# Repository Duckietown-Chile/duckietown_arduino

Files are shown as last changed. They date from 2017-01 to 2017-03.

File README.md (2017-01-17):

# duckietown_arduino

Arduino based controller for Dukietown robots. This library is based on [serial_dxl](https://github.com/rorromr/serial_dxl).

* Microcontroller: ATmega 168 3.3V 8MHz
* Board: Arduino Pro Mini
* H Bridge: Double L9110

| Pin | Function  |
|-----|---|
| 5 | PWM CHA-1B  |
| 6 | PWM CHB-1B  |
| 11  | PWM CHA-1A  |
| 12  | PWM CHB-1A  |

Registros:

| Address | Type | Size | Function |
|---|---|---|---|
| 6 | uint8_t  | 1 | LED (0: off, 1: on) |
| 7 | int16_t  | 2 | PWM channel 1 (-255 to 255)|
| 9 | int16_t  | 2 | PWM channel 1 (-255 to 255)|

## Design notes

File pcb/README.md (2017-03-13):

# Duckiebot Shield

Raspberry Pi 3 Shied thats provide serial communication with Arduino ProMini 328.
Used in Duckiebot for motors and others sensors communication and control.

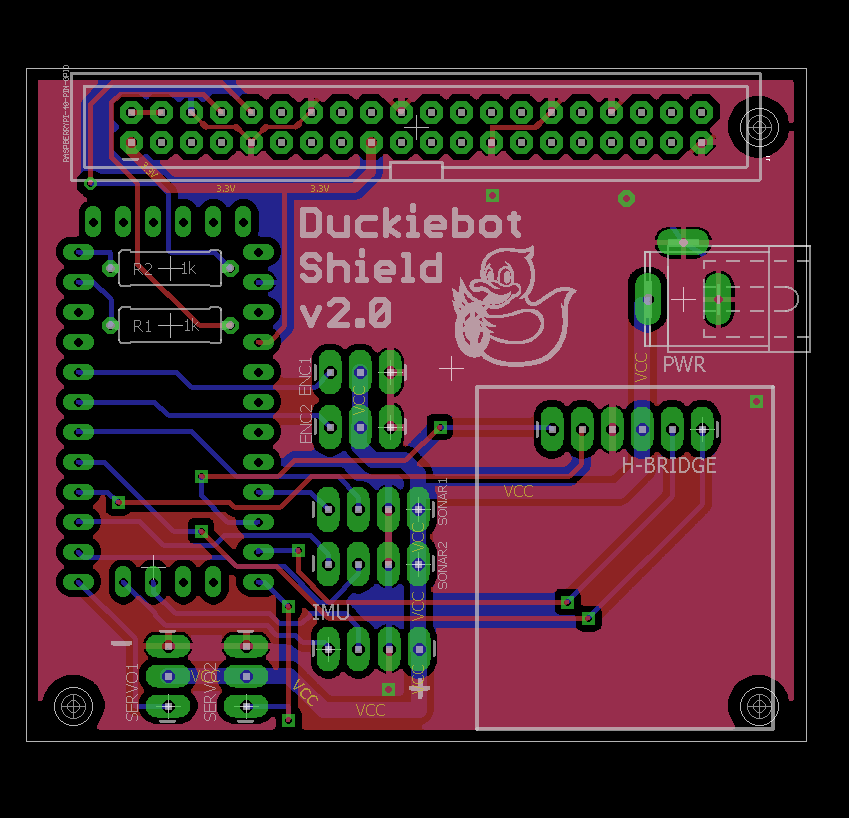
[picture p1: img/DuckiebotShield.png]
duckiebot shield


[duckiebotshield]: https://github.com/Duckietown-Chile/duckietown_arduino/blob/master/img/DuckiebotShield.png

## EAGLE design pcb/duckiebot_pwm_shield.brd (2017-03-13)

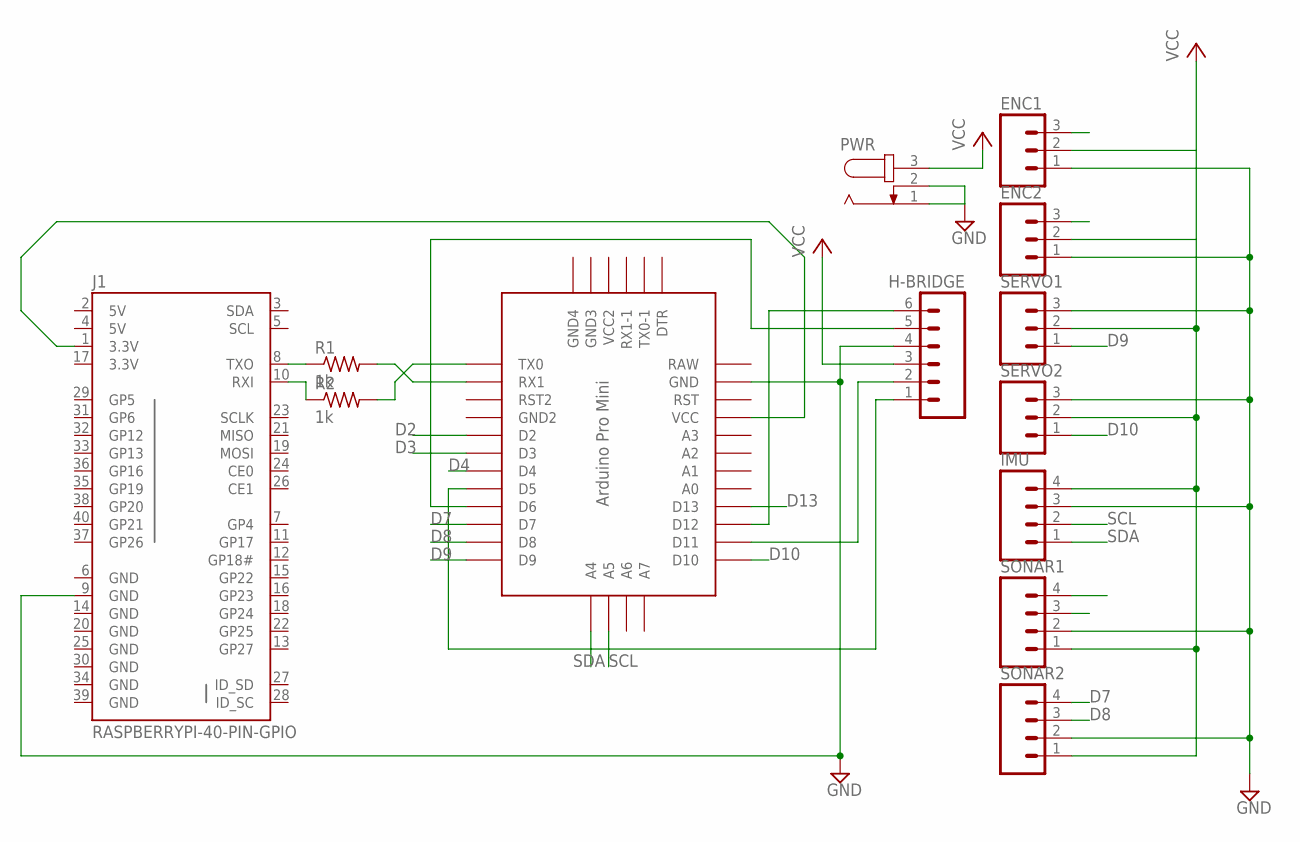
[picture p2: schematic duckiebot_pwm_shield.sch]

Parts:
ENC1, ENC2: M03LONGPADS; 1X03_LONGPADS
H-BRIDGE: M06LONGPADS; 1X06_LONGPADS
IMU: M04LONGPADS; 1X04_LONGPADS
J1: RASPBERRYPI-40-PIN-GPIO; 2X20-SHROUDED
PWR: JACK-PLUG0; SPC4077
R1, R2: 1k; 0309/10
SERVO1, SERVO2: M03LONGPADS; 1X03_LONGPADS
SONAR1, SONAR2: M04LONGPADS; 1X04_LONGPADS
U$2: PRO-MINI

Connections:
3.3V: J1.1 (3.3V), J1.17 (3.3V), U$2.VCC
5V: J1.2 (5V), J1.4 (5V)
A-1A: H-BRIDGE.2, U$2.D11
A-1B: H-BRIDGE.1, U$2.D5
B-1A: H-BRIDGE.6, U$2.D12
B-1B: H-BRIDGE.5, U$2.D6
D2: ENC1.3, U$2.D2
D3: ENC2.3, U$2.D3
D4: SONAR1.3, U$2.D4
D7: SONAR2.4, U$2.D7
D8: SONAR2.3, U$2.D8
D9: SERVO1.1, U$2.D9
D10: SERVO2.1, U$2.D10
D13: SONAR1.4, U$2.D13
GND: ENC1.1, ENC2.1, H-BRIDGE.4, IMU.3, J1.6 (GND), J1.9 (GND), J1.14 (GND), J1.20 (GND), J1.25 (GND), J1.30 (GND), J1.34 (GND), J1.39 (GND), PWR.1, PWR.2, SERVO1.3, SERVO2.3, SONAR1.2, SONAR2.2, U$2.GND
unnamed: R1.2, U$2.RX1
unnamed: R2.2, U$2.TX0
unnamed: J1.10 (RXI), R2.1
unnamed: J1.8 (TXO), R1.1
RAW: U$2.RAW
SCL: IMU.2, U$2.A5
SDA: IMU.1, U$2.A4
VCC: ENC1.2, ENC2.2, H-BRIDGE.3, IMU.4, PWR.3, SERVO1.2, SERVO2.2, SONAR1.1, SONAR2.1

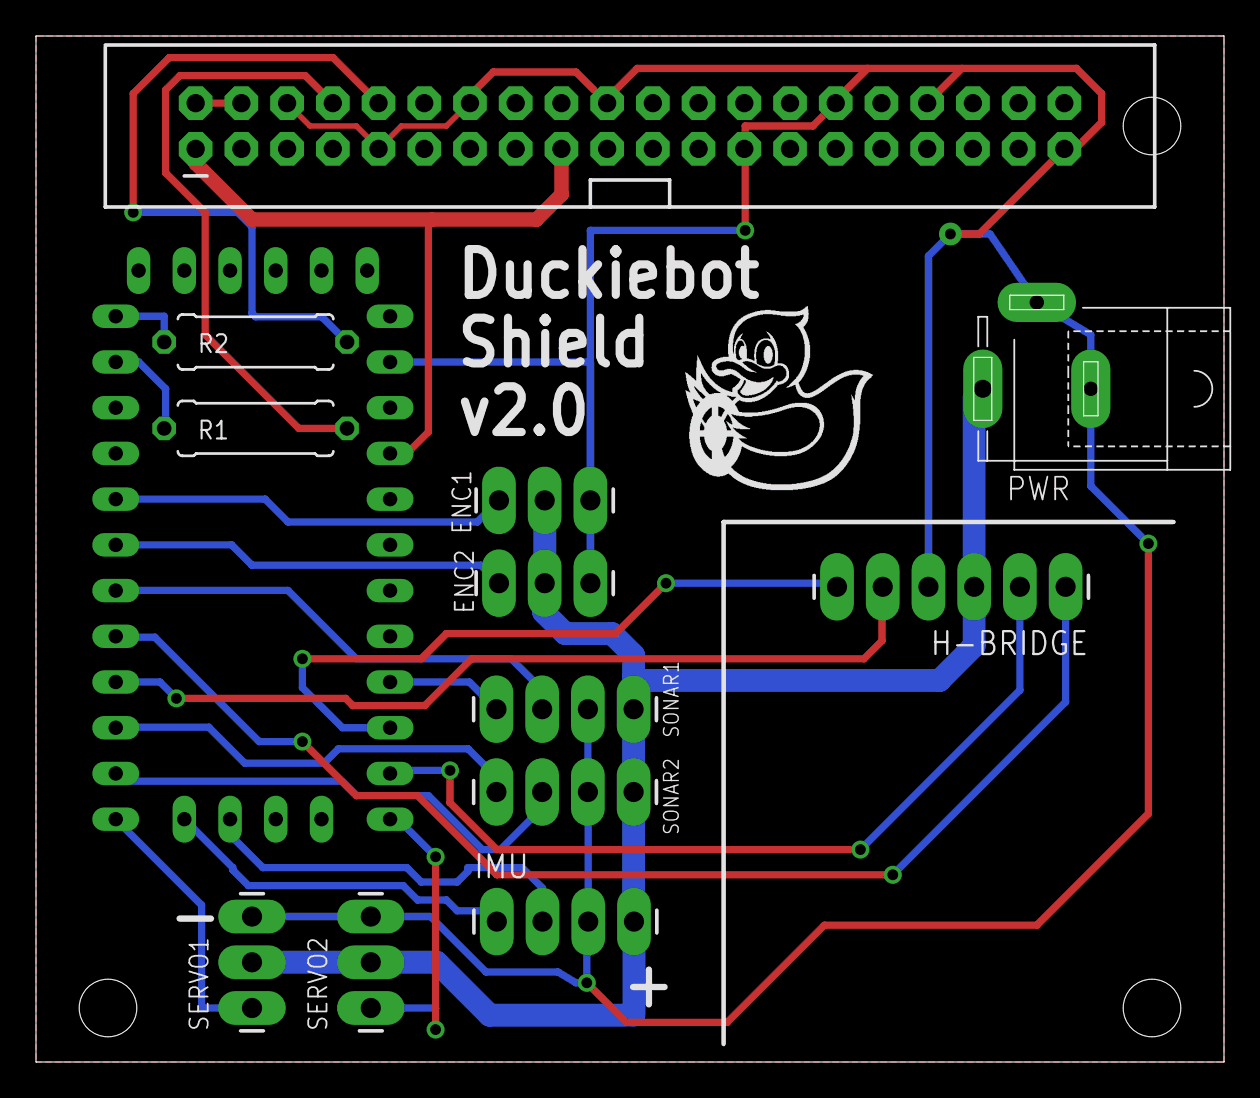
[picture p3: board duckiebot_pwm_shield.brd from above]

Board: 2 copper layers, 66.0 x 57.0 mm, 14 parts (0 on the bottom side), 22 nets.

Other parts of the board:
U$1: DUCK_LOGO

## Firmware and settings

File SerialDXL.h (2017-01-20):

/**
 * @file
 * @brief Dynamixel Device Library
 */
#ifndef SERIALDXL_H
#define SERIALDXL_H

#include "data_serialization.h"
#include "variable.h"
#include "mmap.h"
#include "logger.h"
#include <avr/sleep.h>
#include <Arduino.h>

//------------------------------------------------------------------------------
/**
 * @class DeviceDXL
 * @brief Base class for device with Dynamixel protocol.
 */
template <uint16_t modelT, uint8_t firmwareT, size_t mmap_size>
class DeviceDXL {
  public:
    DeviceDXL():
      model_(MMap::Access::R, MMap::Storage::RAM),
      firmware_(MMap::Access::R, MMap::Storage::RAM),
      id_(MMap::Access::RW, MMap::Storage::RAM),
      baudrate_(MMap::Access::RW, MMap::Storage::RAM),
      return_delay_(MMap::Access::RW, MMap::Storage::RAM),
      mmap_()
    {
    }

    virtual inline bool onReset() = 0;

    virtual inline void setTX() = 0;

    virtual inline void setRX() = 0;

    virtual inline void update() = 0;

    void init()
    {
      mmap_.registerVariable(&model_);
      mmap_.registerVariable(&firmware_);
      mmap_.registerVariable(&id_);
      mmap_.registerVariable(&baudrate_);
      mmap_.registerVariable(&return_delay_);
    }

    void reset()
    {
      if (onReset())
      {
        INFO_PRINTLN("DEVICE RESET");
        mmap_.reset(); // Set default values and save EEPROM
      }
    }

    // Model
    MMap::Variable<UInt16, ConstInt<UInt16::type, 0U>, ConstInt<UInt16::type, 255U>, ConstInt<UInt16::type, modelT> > model_;

    // Firmware version
    MMap::Variable<UInt8, ConstInt<UInt8::type, 0U>, ConstInt<UInt8::type, 255U>, ConstInt<UInt8::type, firmwareT> > firmware_;

    // ID
    MMap::Variable<UInt8, ConstInt<UInt8::type, 0U>, ConstInt<UInt8::type, 255U>, ConstInt<UInt8::type, 1U> > id_;

    // Baudrate
    MMap::Variable<UInt8, ConstInt<UInt8::type, 0U>, ConstInt<UInt8::type, 255U>, ConstInt<UInt8::type, 1U> > baudrate_;

    // Return dalay time
    MMap::Variable<UInt8, ConstInt<UInt8::type, 0U>, ConstInt<UInt8::type, 255U>, ConstInt<UInt8::type, 250U> > return_delay_;

    // Memory mapping
    MMap::MMap<5+mmap_size> mmap_;
};
//------------------------------------------------------------------------------
/**
 * @class SerialDXL
 * @brief Serial port wrapper for DXL communication protocol.
 */

// Max message length, used for buffers
#define SERIALDXL_MSG_LENGTH 64

template <typename DeviceT>
class SerialDXL
{
  public:
    SerialDXL():
      msgState_(0U),
      msgParamIdx_(2U),
      msgLen_(0U),
      msgFinish_(0U),
      msgChecksum_(0U),
      error_(0U),
      last_call_(0UL)
    {
    }

    /**
     * @brief Initialize SerialDXL. Set baudrate and target device.
     * @details 
     * 
     * @param baud Baudrate using Dynamixel format.
     * @param port Serial port (Stream class).
     * @param device Target device.
     */
    void init(HardwareSerial *port, DeviceT *device)
    {
      // Set DeviceDXL
      device_ = device;
      // Set serial port
      port_ = port;
      // Set baudrate using Dynamixel relation
      //uint32_t baud = F_CPU/8/(device_->baudrate_.data+1);
      
      //port_->begin(115200);
      INFO_PRINT("Baudrate at: "); INFO_PRINTLN(9600);
    }

    /**
     * @brief Process data from Serial 
     * @details Add data to buffers
     * 
     * @param data Data from Serial port.
     */
    void process(uint8_t data)
    {
      DEBUG_PRINTLN(data);
      // Check message
      uint32_t now = millis();
      if (now - last_call_ > 100)
      {
        // Reset states
        DEBUG_PRINTLN("RESET MSG");
        msgState_ = 0;
        msgParamIdx_ = 2;
        msgLen_ = 0;
        msgChecksum_ = 0;
        msgFinish_ = 0;
      }
      last_call_ = now;

      switch(msgState_)
      {
        case 0: // 0xFF
          msgState_ = data == 0xFF ? 1 : 0;
          break;
          
        case 1: // 0XFF
          msgState_ = data == 0xFF ? 2 : 1;
          break;
          
        case 2: // ID
          // Check error
          msgState_ = data == device_->id_.data ? 3 : 0;
          break;
          
        case 3: // Length
          DEBUG_PRINTLN("MSG RECEIVED");
          msgLen_ = data;
          // Checksum
          msgChecksum_ += device_->id_.data + data;
          // Save length in the RX message buffer
          rxMsgBuf_[0] = data;
          msgState_ = 4;
          break;

        case 4: // Instruction
          // Save instruction in the RX message buffer
          rxMsgBuf_[1] = data;
          // Checksum
          msgChecksum_ += data;
          // Check for short message
          msgState_ = msgLen_ <= 2 ? 6 : 5;
          break;
        
        case 5: // Parameters
          rxMsgBuf_[msgParamIdx_++] = data;
          // Checksum
          msgChecksum_ += data;
          // Check message length
          msgState_ = msgParamIdx_ >= msgLen_ ? 6 : msgState_;
          break;

        case 6: // Checksum
          rxMsgBuf_[msgParamIdx_] = data;
          // Check
          msgFinish_ = ((uint8_t)(~msgChecksum_))==data;
          // Reset states
          msgState_ = 0;
          msgParamIdx_ = 2;
          msgChecksum_ = 0;
          msgLen_ = 0;
          break;
      }

      // Process message
      if (msgFinish_)
      {
        DEBUG_PRINTLN("MSG RECEIVED SUCCESS");
        uint8_t i, data, checksum;
        switch(rxMsgBuf_[1])
        {
          case 1: // Ping
            txMsgBuf_[0] = 0xFF;
            txMsgBuf_[1] = 0xFF;
            txMsgBuf_[2] = device_->id_.data; //ID 
            txMsgBuf_[3] = 2; // Length
            txMsgBuf_[4] = 0; // Error
            txMsgBuf_[5] = ~(txMsgBuf_[2]+txMsgBuf_[3]);
            // Status return delay
            delayMicroseconds(2*device_->return_delay_.data);
            device_->setTX();
            // Send
            port_->write(txMsgBuf_,6);
            port_->flush(); // Wait to complete
            device_->setRX();
            msgFinish_ = 0;
            break;

          case 2: // Read data
            DEBUG_PRINTLN("READ DATA");
            txMsgBuf_[0] = 0xFF;
            txMsgBuf_[1] = 0xFF;
            txMsgBuf_[2] = device_->id_.data; //ID 
            txMsgBuf_[3] = 2U+rxMsgBuf_[3]; // Length
            txMsgBuf_[4] = 0U; // Error
            // Reset checksum
            checksum = 0U;
            // Fill buffer
            for (i = 0U; i < rxMsgBuf_[3]; ++i)
            {
              data = device_->mmap_.get(rxMsgBuf_[2]+i);
              checksum += data;
              txMsgBuf_[5+i] = data;
            }
            // Checksum
            txMsgBuf_[5+i] = ~(txMsgBuf_[2]+txMsgBuf_[3]+txMsgBuf_[4]+checksum);
            // Status return delay
            delayMicroseconds(2*device_->return_delay_.data);

            device_->setTX();
            // Send
            DEBUG_PRINTLN(6+i);
            port_->write(txMsgBuf_, 6+i);
            port_->flush(); // Wait to complete

            device_->setRX();
            msgFinish_ = 0;
            break;
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

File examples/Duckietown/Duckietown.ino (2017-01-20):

#define LOGGER_MIN_SEVERITY LOGGER_SEVERITY_NONE
#include <SerialDXL.h>

// Duck basic config
#define DUCK_MODEL 100
#define DUCK_FIRMWARE 100
#define DUCK_MMAP_SIZE 3 // Use 3 variable

// Duck pins
#define DUCK_LED 13
#define DUCK_A_1B 5
#define DUCK_B_1B 6
#define DUCK_A_1A 11
#define DUCK_B_1A 12

/**
 * @brief Duck control using DXL communication protocol
 * 
 */
class Duck: public DeviceDXL<DUCK_MODEL, DUCK_FIRMWARE, DUCK_MMAP_SIZE>
{
  public:
    Duck():
    DeviceDXL(), // Call parent constructor
    command_(MMap::Access::RW, MMap::Storage::RAM), // Led command
    pwmCh1_(MMap::Access::RW, MMap::Storage::RAM), // PWM channel 1 command
    pwmCh2_(MMap::Access::RW, MMap::Storage::RAM) // PWM channel 2 command
    {
      // Config pins
      pinMode(DUCK_LED, OUTPUT);
      pinMode(DUCK_A_1B, OUTPUT);
      pinMode(DUCK_A_1A, OUTPUT);
      pinMode(DUCK_B_1B, OUTPUT);
      pinMode(DUCK_B_1A, OUTPUT);
    }

    void init()
    {
      DEBUG_PRINTLN("INIT");
      /*
       * Register variables
       */
      DeviceDXL::init();
      mmap_.registerVariable(&command_);
      mmap_.registerVariable(&pwmCh1_);
      mmap_.registerVariable(&pwmCh2_);
      mmap_.init();
      
      /*
       * Load default values
       */
      DEBUG_PRINTLN("Load default");
      mmap_.load(); // Load values from EEPROM
      DEBUG_PRINT("data: ");DEBUG_PRINTLN(command_.data);
      INFO_PRINT("id: ");INFO_PRINTLN_RAW(id_.data);
      
      /*
       * Read sensor data
       * e.g. Use ADC, check buttons, etc.
       */
    }

    void update()
    {
      // LED Update
      uint8_t ledCmd = command_.data == 1U ? HIGH : LOW;
      digitalWrite(DUCK_LED, ledCmd);

      // PWM Channel A update
      uint8_t forwardCmd = pwmCh1_.data > 0 ? HIGH : LOW;
      uint8_t duty = forwardCmd == HIGH ? pwmCh1_.data : -pwmCh1_.data;
      digitalWrite(DUCK_A_1A, forwardCmd);
      analogWrite(DUCK_A_1B, duty);

      // PWM Channel B update
      forwardCmd = pwmCh2_.data > 0 ? HIGH : LOW;
      duty = forwardCmd == HIGH ? pwmCh2_.data : -pwmCh2_.data;
      digitalWrite(DUCK_B_1A, forwardCmd);
      analogWrite(DUCK_B_1B, duty);
    }

    inline bool onReset(){;}

    inline void setTX(){;}

    inline void setRX(){;}

  private:    
    // LED variable
    MMap::Integer<UInt8, 0, 1, 1>::type command_;
    // PWM channels
    MMap::Integer<Int16, -255, 255, 0>::type pwmCh1_;
    MMap::Integer<Int16, -255, 255, 0>::type pwmCh2_;
};


Duck duck;
SerialDXL<Duck> serialDxl;

void setup() {
  Serial.begin(57600);
  duck.init();
  duck.reset();
  duck.mmap_.serialize();

  // Init serial communication using Dynamixel format
  serialDxl.init(&Serial ,&duck);
  
}

void loop() {
  // Update msg buffer
  while (Serial.available()){
    serialDxl.process(Serial.read());
  }
  
  duck.mmap_.deserialize();
  duck.update();
  duck.mmap_.serialize();
  
}

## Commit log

2017-01-10 Test PWM
2017-01-17 eeprom and null reset functions
    [Duckietown.ino, SerialDXL.h]
2017-01-17 Mount images
2017-01-18 duckiebot pcb v1.0
    [duckiebot_pwm_shield.brd, duckiebot_pwm_shield.sch]
2017-01-20 Fix baudrate for ATmega168
    [Duckietown.ino, SerialDXL.h]
2017-01-20 Fix pwm condition
2017-01-23 duckiebot shield updated v1.1
    [duckiebot_pwm_shield.brd, duckiebot_pwm_shield.sch]
2017-01-23 duckiebot shield v1.2, duck missing :(
    [duckiebot_pwm_shield.brd, duckiebot_pwm_shield.sch]
2017-01-23 v1.3, falta arreglar el layer del pato ql
    [duckiebot_pwm_shield.brd, duckiebot_pwm_shield.sch]
2017-01-24 fixed resistor size, v1.4 ready to build
    [duckiebot_pwm_shield.brd, duckiebot_pwm_shield.sch]
2017-03-13 added pcb image
    [duckiebot_pwm_shield.brd]

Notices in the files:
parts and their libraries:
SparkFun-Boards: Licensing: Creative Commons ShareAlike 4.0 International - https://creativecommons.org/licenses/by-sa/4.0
